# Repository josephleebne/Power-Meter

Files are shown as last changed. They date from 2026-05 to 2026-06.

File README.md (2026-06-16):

# Power Meter

This repository is a  mirror of a team project developed for **ENGG2800**. 

A high precision digital power meter designed to sample voltage and current telemetry from a load, calculate real time electrical parameters, and stream data to a localised GUI for monitoring and analysis. The system bridges custom hardware instrumentation with embedded processing and local host application interfaces.

### Finished Prototype
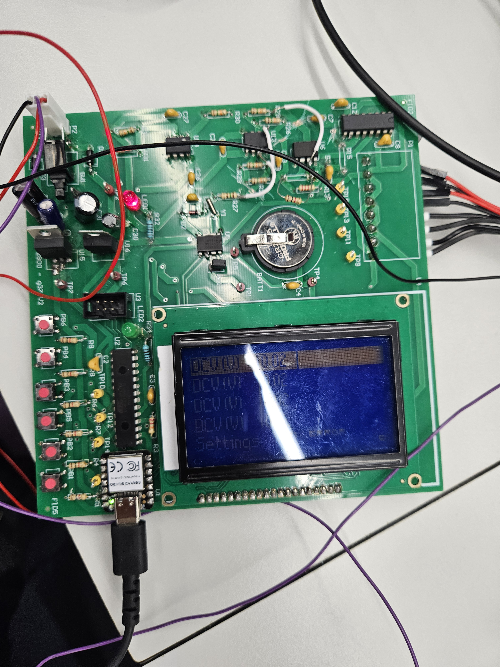
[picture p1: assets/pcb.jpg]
Finished Power Meter Prototype


### Hardware Documentation
* [PCB Artwork (PDF)](./assets/PCB_Artwork.pdf)

## The Engineering Team & Contributions

This project was developed by a collaborative 4 person engineering team. Individual technical ownership is broken down below:

* **Joseph Lee (Firmware & Analogue Electronics Engineer):** Engineered the core measurement firmware, designed and implemented the signal conditioning analogue circuits, and performed the final hardware schematic and PCB design audits to ensure production compliance. Compiled and structured the final engineering Bill of Materials.
* **Software Engineer:** Developed the desktop Graphical User Interface (GUI), built the data parsing serial communication protocols, and integrated secondary hardware timekeeping features.
* **Display Systems Engineer:** Owned the low level firmware drivers and hardware interfacing for the localised system LCD menus.
* **PCB Design Engineer:** Handled the physical PCB layout routing, electronic component soldering, and implemented safe switching circuitry for wide-range current measurements.

## My Contributions

### 1. Analogue Measurement Circuit Design
* **Signal Conditioning:** Designed and implemented a five stage pipeline matching analogue to digital converter constraints to safely process AC and DC voltage and current waveforms.
* **Iterative Prototyping:** Conducted rigorous breadboard testing and design iterations to select optimal scaling and biasing topologies (See the beautiful chaos below).

### Breadboard Prototyping and Validation Stage
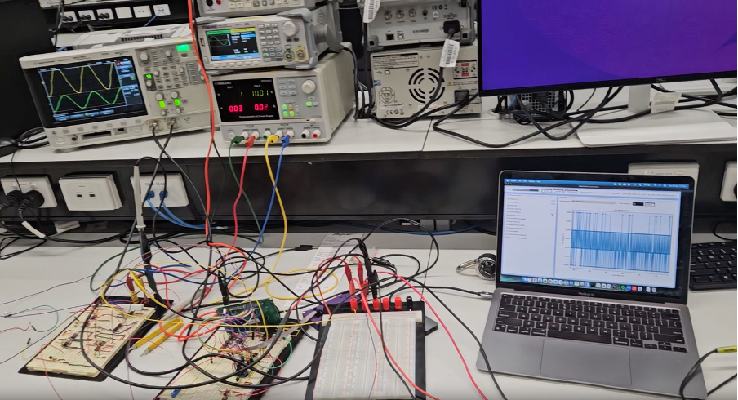
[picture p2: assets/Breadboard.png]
Breadboard Prototyping and Validation Stage


* **Hardware Debugging:** Resolved circuit loading effects by introducing active operational amplifier buffering stages.
* **Power Subsystem Redesign:** Eliminated amplifier saturation by upgrading supply rails to 10V and integrating a 5V regulator for the ATmega microcontroller and display.
* **Simulation:** Modelled all AC and DC measurement circuits using simulation software to validate operational theory prior to production.

### 2. Measurement Firmware Engineering
* **Architecture:** Developed an interrupt based sampling architecture to ensure deterministic data collection and system responsiveness.
* **Signal Processing:** Implemented low level firmware executing real time calculations, transitioning raw data into True Root Mean Square accumulation loops.
* **Precision Metrics:** Engineered efficient firmware routines to calculate frequency, power factor, and phase angles.
* **Data Streaming:** Designed serial communication protocols to stream calculated telemetry data to the host interface.

### 3. PCB Review and Documentation
* **Design Audits:** Spearheaded comprehensive hardware schematic reviews against technical standards to prevent layout errors.
* **BOM Generation:** Compiled the final engineering Bill of Materials, cross referencing datasheets to guarantee exact footprint matches and proper component sourcing.

#### Bill of Materials (BOM)
* [BOM](./assets/BOM.pdf)

## Repository Architecture

The codebase has been stripped of legacy test files and is organised strictly around the deliverables:
```text
Power-Meter/
├── .gitignore
├── embedded/           # Firmwire Files
│   ├── lcd/            # Display drivers
│   └── measurement.X/  # Core firmware workspace
└── lab_pc/             # GUI Files
│    └── GUI_new.py      # Python based user interface for telemetry rendering
│
├── PCB/                # Altium Designer Project

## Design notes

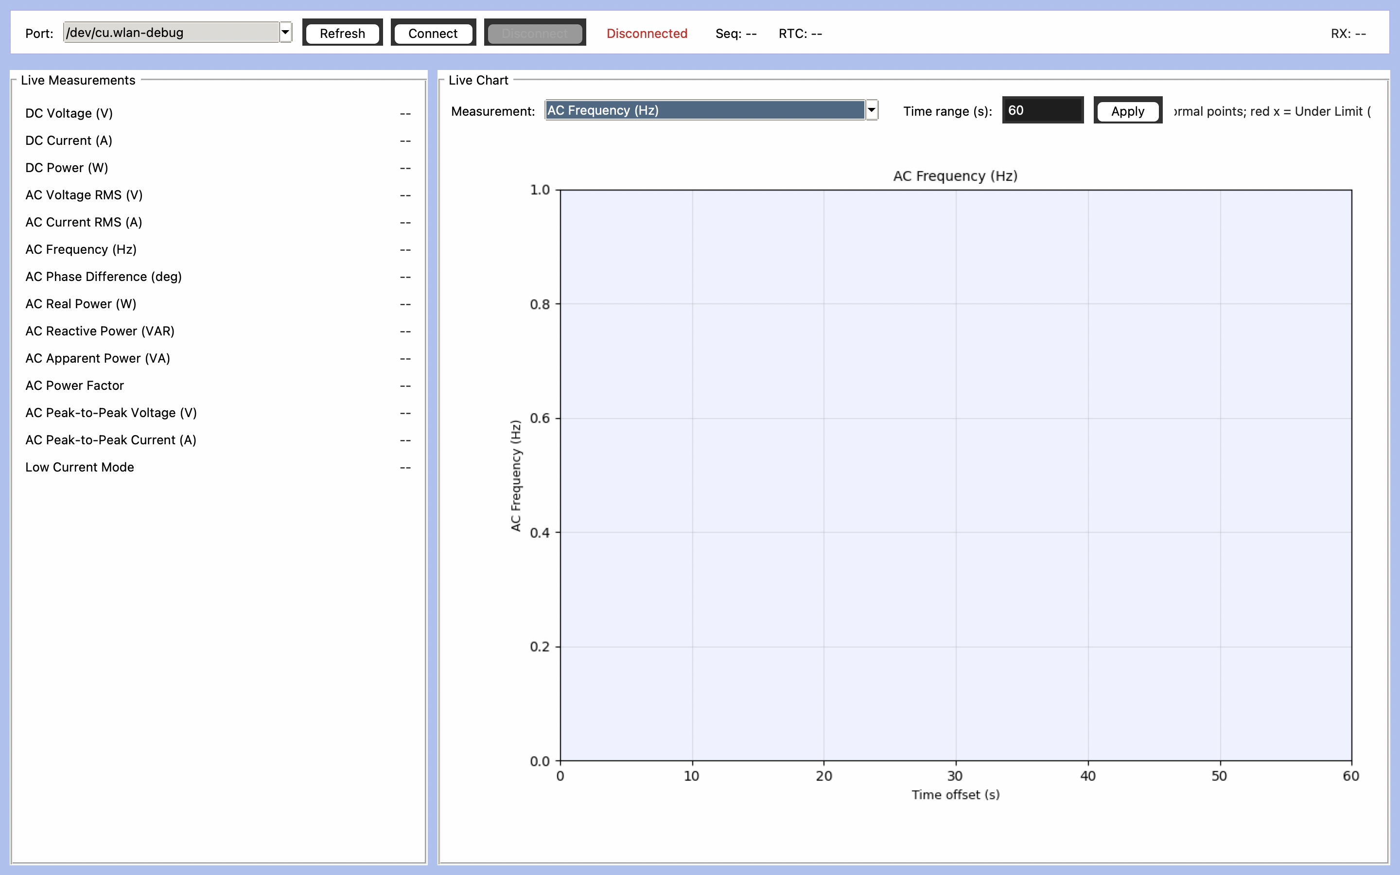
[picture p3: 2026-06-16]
assets/GUI.png

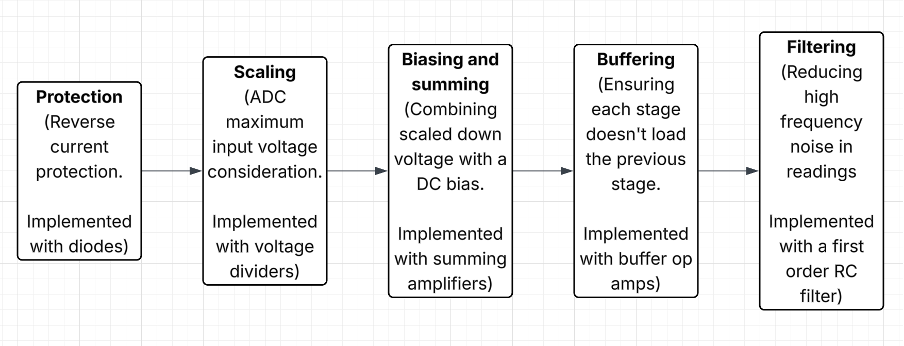
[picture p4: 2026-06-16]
assets/Signal_Conditioning_Pipeline.png

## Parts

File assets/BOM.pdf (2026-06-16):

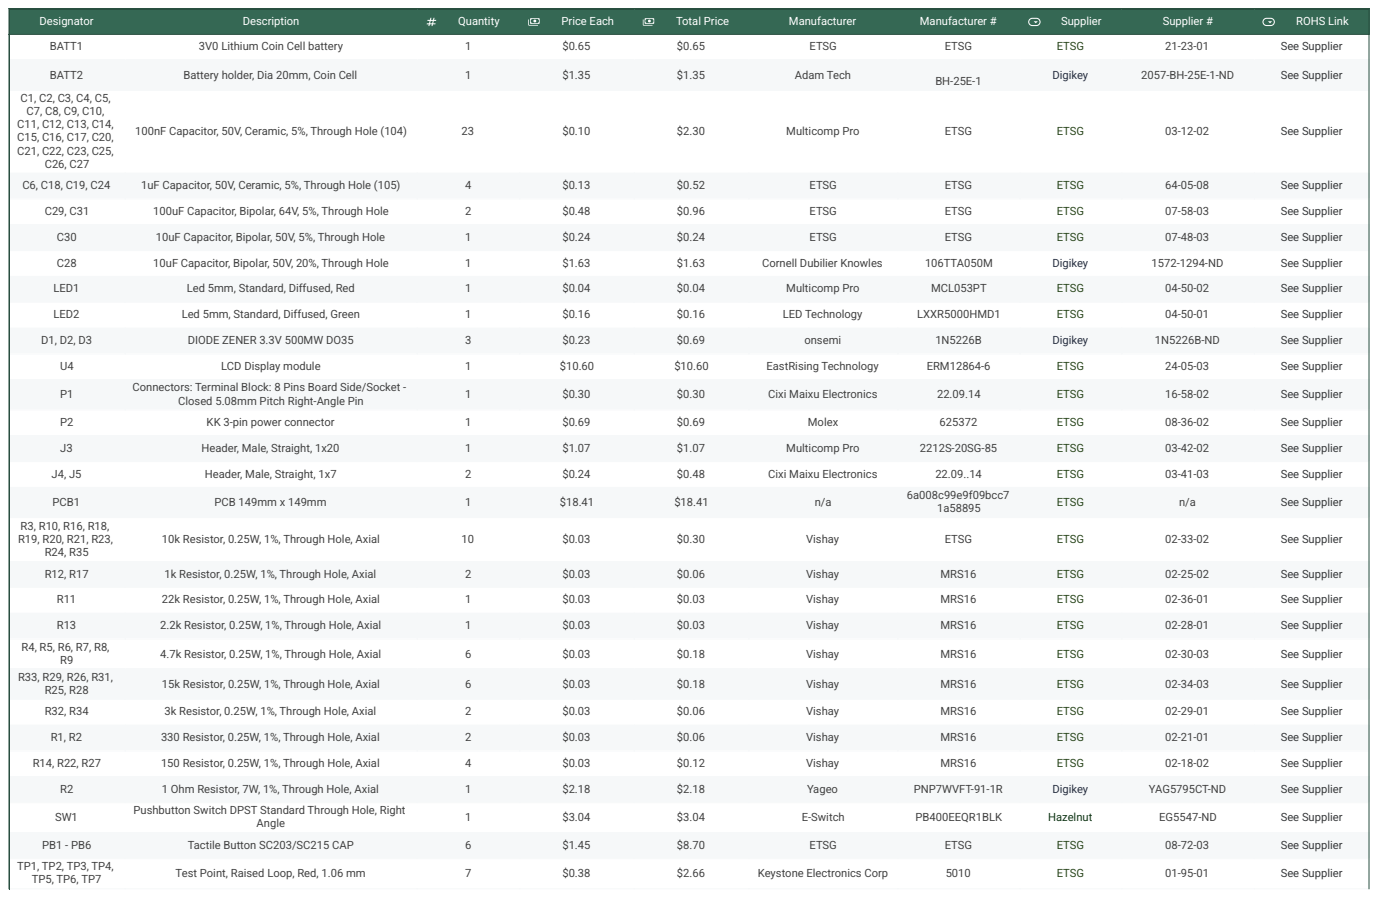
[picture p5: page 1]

Designator | Description | Quantity | Price Each | Total Price | Manufacturer | Manufacturer # | Supplier | Supplier # | ROHS Link

BATT1 | 3V0 Lithium Coin Cell battery | 1 | $0.65 | $0.65 | ETSG | ETSG | ETSG | 21-23-01 | See Supplier

BATT2 | Battery holder, Dia 20mm, Coin Cell | 1 | $1.35 | $1.35 | Adam Tech | BH-25E-1 | Digikey | 2057-BH-25E-1-ND | See Supplier

C1, C2, C3, C4, C5, C7, C8, C9, C10, C11, C12, C13, C14, C15, C16, C17, C20, C21, C22, C23, C25, C26, C27 | 100nF Capacitor, 50V, Ceramic, 5%, Through Hole (104) | 23 | $0.10 | $2.30 | Multicomp Pro | ETSG | ETSG | 03-12-02 | See Supplier

C6, C18, C19, C24 | 1uF Capacitor, 50V, Ceramic, 5%, Through Hole (105) | 4 | $0.13 | $0.52 | ETSG | ETSG | ETSG | 64-05-08 | See Supplier

C29, C31 | 100uF Capacitor, Bipolar, 64V, 5%, Through Hole | 2 | $0.48 | $0.96 | ETSG | ETSG | ETSG | 07-58-03 | See Supplier

C30 | 10uF Capacitor, Bipolar, 50V, 5%, Through Hole | 1 | $0.24 | $0.24 | ETSG | ETSG | ETSG | 07-48-03 | See Supplier

C28 | 10uF Capacitor, Bipolar, 50V, 20%, Through Hole | 1 | $1.63 | $1.63 | Cornell Dubilier Knowles | 106TTA050M | Digikey | 1572-1294-ND | See Supplier

LED1 | Led 5mm, Standard, Diffused, Red | 1 | $0.04 | $0.04 | Multicomp Pro | MCL053PT | ETSG | 04-50-02 | See Supplier

LED2 | Led 5mm, Standard, Diffused, Green | 1 | $0.16 | $0.16 | LED Technology | LXXR5000НMD1 | ETSG | 04-50-01 | See Supplier

D1, D2, D3 | DIODE ZENER 3.3V 500MW DO35 | 3 | $0.23 | $0.69 | onsemi | 1N5226B | Digikey | 1N5226B-ND | See Supplier

U4 | LCD Display module | 1 | $10.60 | $10.60 | EastRising Technology | ERM12864-6 | ETSG | 24-05-03 | See Supplier

P1 | Connectors: Terminal Block: 8 Pins Board Side/Socket -Closed 5.08mm Pitch Right-Angle Pin | 1 | $0.30 | $0.30 | Cixi Maixu Electronics | 22.09.14 | ETSG | 16-58-02 | See Supplier

P2 | KK 3-pin power connector | 1 | $0.69 | $0.69 | Molex | 625372 | ETSG | 08-36-02 | See Supplier

J3 | Header, Male, Straight, 1x20 | 1 | $1.07 | $1.07 | Multicomp Pro | 2212S-20SG-85 | ETSG | 03-42-02 | See Supplier

J4, J5 | Header, Male, Straight, 1x7 | 2 | $0.24 | $0.48 | Cixi Maixu Electronics | 22.09..14 | ETSG | 03-41-03 | See Supplier

PCB1 | PCB 149mm x 149mm | 1 | $18.41 | $18.41 | n/a | 6a008c99e9f09bcc7 1a58895 | ETSG | n/a | See Supplier

R3, R10, R16, R18, R19, R20, R21, R23, R24, R35 | 10k Resistor, 0.25W, 1%, Through Hole, Axial | 10 | $0.03 | $0.30 | Vishay | ETSG | ETSG | 02-33-02 | See Supplier

R12, R17 | 1k Resistor, 0.25W, 1%, Through Hole, Axial | 2 | $0.03 | $0.06 | Vishay | MRS16 | ETSG | 02-25-02 | See Supplier

R11 | 22k Resistor, 0.25W, 1%, Through Hole, Axial | 1 | $0.03 | $0.03 | Vishay | MRS16 | ETSG | 02-36-01 | See Supplier

R13 | 2.2k Resistor, 0.25W, 1%, Through Hole, Axial | 1 | $0.03 | $0.03 | Vishay | MRS16 | ETSG | 02-28-01 | See Supplier

R4, R5, R6, R7, R8, R9 | 4.7k Resistor, 0.25W, 1%, Through Hole, Axial | 6 | $0.03 | $0.18 | Vishay | MRS16 | ETSG | 02-30-03 | See Supplier

R33, R29, R26, R31, R25, R28 | 15k Resistor, 0.25W, 1%, Through Hole, Axial | 6 | $0.03 | $0.18 | Vishay | MRS16 | ETSG | 02-34-03 | See Supplier

R32, R34 | 3k Resistor, 0.25W, 1%, Through Hole, Axial | 2 | $0.03 | $0.06 | Vishay | MRS16 | ETSG | 02-29-01 | See Supplier

R1, R2 | 330 Resistor, 0.25W, 1%, Through Hole, Axial | 2 | $0.03 | $0.06 | Vishay | MRS16 | ETSG | 02-21-01 | See Supplier

R14, R22, R27 | 150 Resistor, 0.25W, 1%, Through Hole, Axial | 4 | $0.03 | $0.12 | Vishay | MRS16 | ETSG | 02-18-02 | See Supplier

R2 | 1 Ohm Resistor, 7W, 1%, Through Hole, Axial | 1 | $2.18 | $2.18 | Yageo | PNP7WVFT-91-1R | Digikey | YAG5795CT-ND | See Supplier

SW1 | Pushbutton Switch DPST Standard Through Hole, Right Angle | 1 | $3.04 | $3.04 | E-Switch | PB400EEQR1BLK | Hazelnut | EG5547-ND | See Supplier

PB1 - PB6 | Tactile Button SC203/SC215 CAP | 6 | $1.45 | $8.70 | ETSG | ETSG | ETSG | 08-72-03 | See Supplier

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

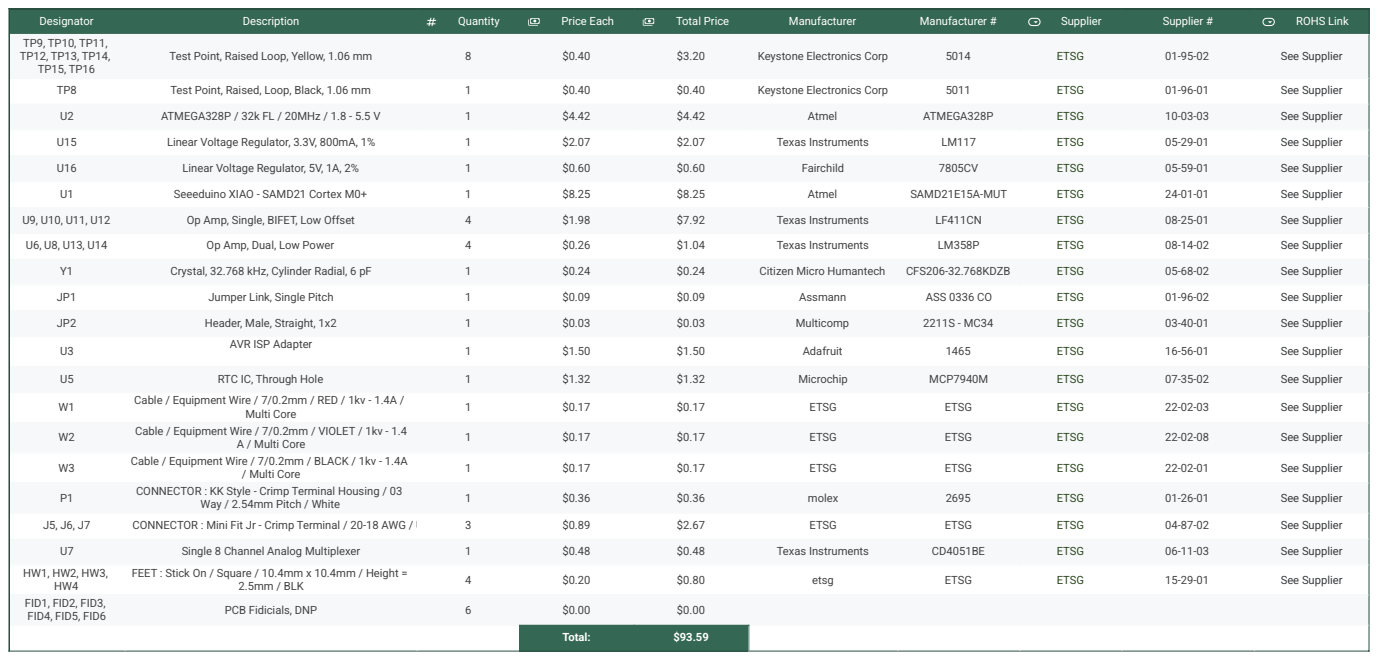
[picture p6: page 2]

Designator | Description | Quantity | Price Each | Total Price | Manufacturer | Manufacturer # | Supplier | Supplier # | ROHS Link

TP9, TP10, TP11, TP12, TP13, TP14, TP15, TP16 | Test Point, Raised Loop, Yellow, 1.06 mm | 8 | $0.40 | $3.20 | Keystone Electronics Corp | 5014 | ETSG | 01-95-02 | See Supplier

TP8 | Test Point, Raised, Loop, Black, 1.06 mm | 1 | $0.40 | $0.40 | Keystone Electronics Corp | 5011 | ETSG | 01-96-01 | See Supplier

U2 | ATMEGA328P / 32k FL / 20MHz / 1.8 - 5.5 V | 1 | $4.42 | $4.42 | Atmel | ATMEGA328P | ETSG | 10-03-03 | See Supplier

U15 | Linear Voltage Regulator, 3.3V, 800mA, 1% | 1 | $2.07 | $2.07 | Texas Instruments | LM117 | ETSG | 05-29-01 | See Supplier

U16 | Linear Voltage Regulator, 5V, 1A, 2% | 1 | $0.60 | $0.60 | Fairchild | 7805CV | ETSG | 05-59-01 | See Supplier

U1 | Seeeduino XIAO - SAMD21 Cortex M0+ | 1 | $8.25 | $8.25 | Atmel | SAMD21E15A-MUT | ETSG | 24-01-01 | See Supplier

U9, U10, U11, U12 | Op Amp, Single, BIFET, Low Offset | 4 | $1.98 | $7.92 | Texas Instruments | LF411CN | ETSG | 08-25-01 | See Supplier

U6, U8, U13, U14 | Op Amp, Dual, Low Power | 4 | $0.26 | $1.04 | Texas Instruments | LM358P | ETSG | 08-14-02 | See Supplier

Y1 | Crystal, 32.768 kHz, Cylinder Radial, 6 pF | 1 | $0.24 | $0.24 | Citizen Micro Humantech | CFS206-32.768KDZB | ETSG | 05-68-02 | See Supplier

JP1 | Jumper Link, Single Pitch | 1 | $0.09 | $0.09 | Assmann | ASS 0336 CO | ETSG | 01-96-02 | See Supplier

JP2 | Header, Male, Straight, 1x2 | 1 | $0.03 | $0.03 | Multicomp | 2211S - MC34 | ETSG | 03-40-01 | See Supplier

U3 | AVR ISP Adapter | 1 | $1.50 | $1.50 | Adafruit | 1465 | ETSG | 16-56-01 | See Supplier

U5 | RTC IC, Through Hole | 1 | $1.32 | $1.32 | Microchip | MCP7940M | ETSG | 07-35-02 | See Supplier

W1 | Cable / Equipment Wire / 7/0.2mm / RED / 1kv - 1.4A / Multi Core | 1 | $0.17 | $0.17 | ETSG | ETSG | ETSG | 22-02-03 | See Supplier

W2 | Cable / Equipment Wire / 7/0.2mm / VIOLET / 1kv - 1.4 A / Multi Core | 1 | $0.17 | $0.17 | ETSG | ETSG | ETSG | 22-02-08 | See Supplier

W3 | Cable / Equipment Wire / 7/0.2mm / BLACK / 1kv - 1.4A / Multi Core | 1 | $0.17 | $0.17 | ETSG | ETSG | ETSG | 22-02-01 | See Supplier

P1 | CONNECTOR : KK Style - Crimp Terminal Housing / 03 Way / 2.54mm Pitch / White | 1 | $0.36 | $0.36 | molex | 2695 | ETSG | 01-26-01 | See Supplier

J5, J6, J7 | CONNECTOR : Mini Fit Jr - Crimp Terminal / 20-18 AWG / Use Crimp Tool K271 3 | | $0.89 | $2.67 | ETSG | ETSG | ETSG | 04-87-02 | See Supplier

U7 | Single 8 Channel Analog Multiplexer | 1 | $0.48 | $0.48 | Texas Instruments | CD4051BE | ETSG | 06-11-03 | See Supplier

HW1, HW2, HW3, HW4 | FEET : Stick On / Square / 10.4mm x 10.4mm / Height = 2.5mm / BLK | 4 | $0.20 | $0.80 | etsg | ETSG | ETSG | 15-29-01 | See Supplier

FID1, FID2, FID3, FID4, FID5, FID6 | PCB Fidicials, DNP | 6 | $0.00 | $0.00

Total: | $93.59

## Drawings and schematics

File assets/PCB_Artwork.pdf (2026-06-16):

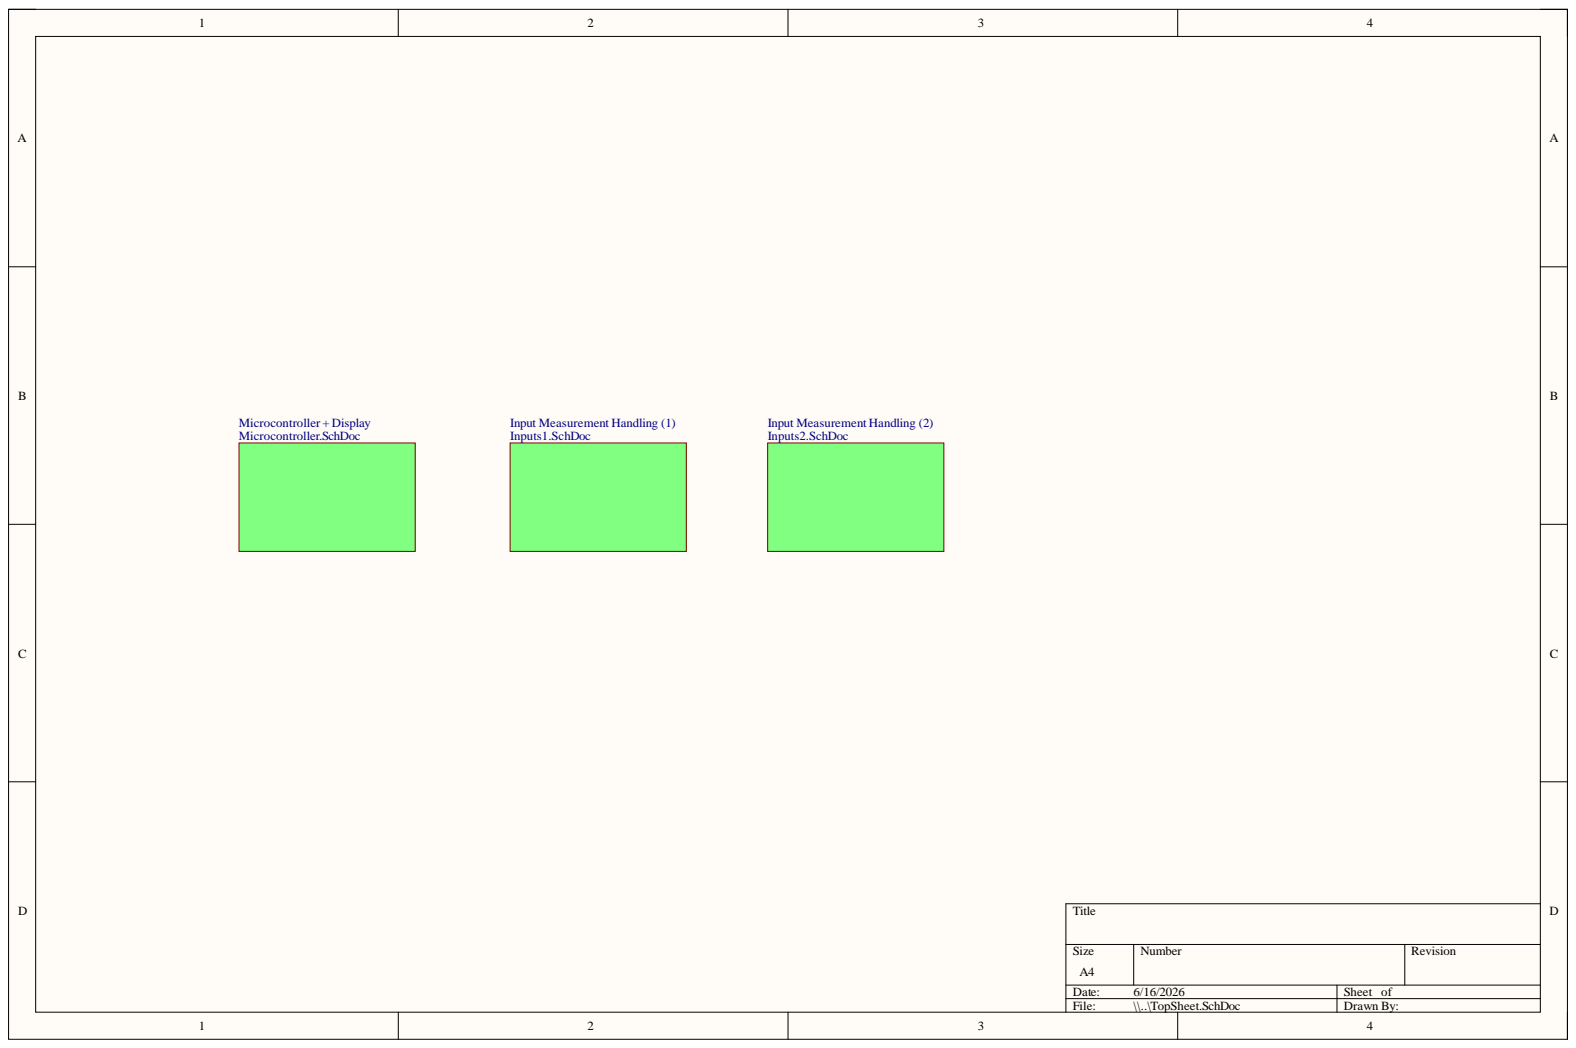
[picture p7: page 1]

Size A4 | Number | Revision

Date: 6/16/2026 | Sheet of
File: \\..\TopSheet.SchDoc | Drawn By:

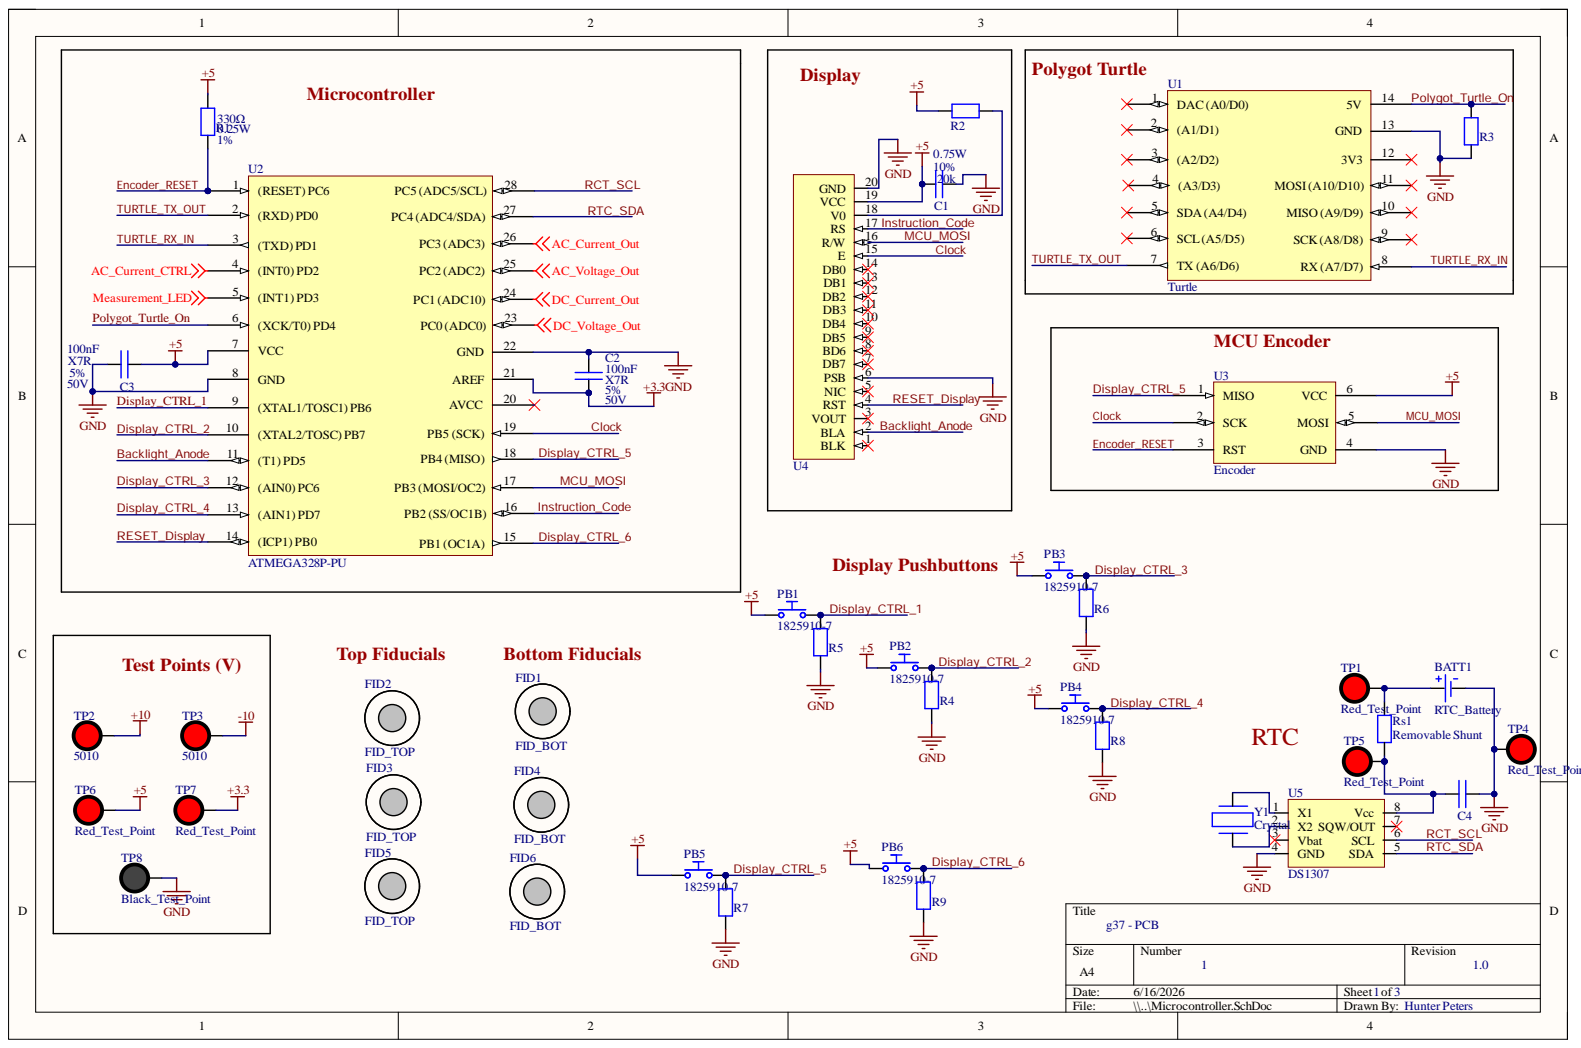
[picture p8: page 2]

Da te : 6/16/202 6 | She et of 1 3
File : \\. .\Mic rocontroll e r . S c hD o c | Dr awn B y : Hunte r P e te r s

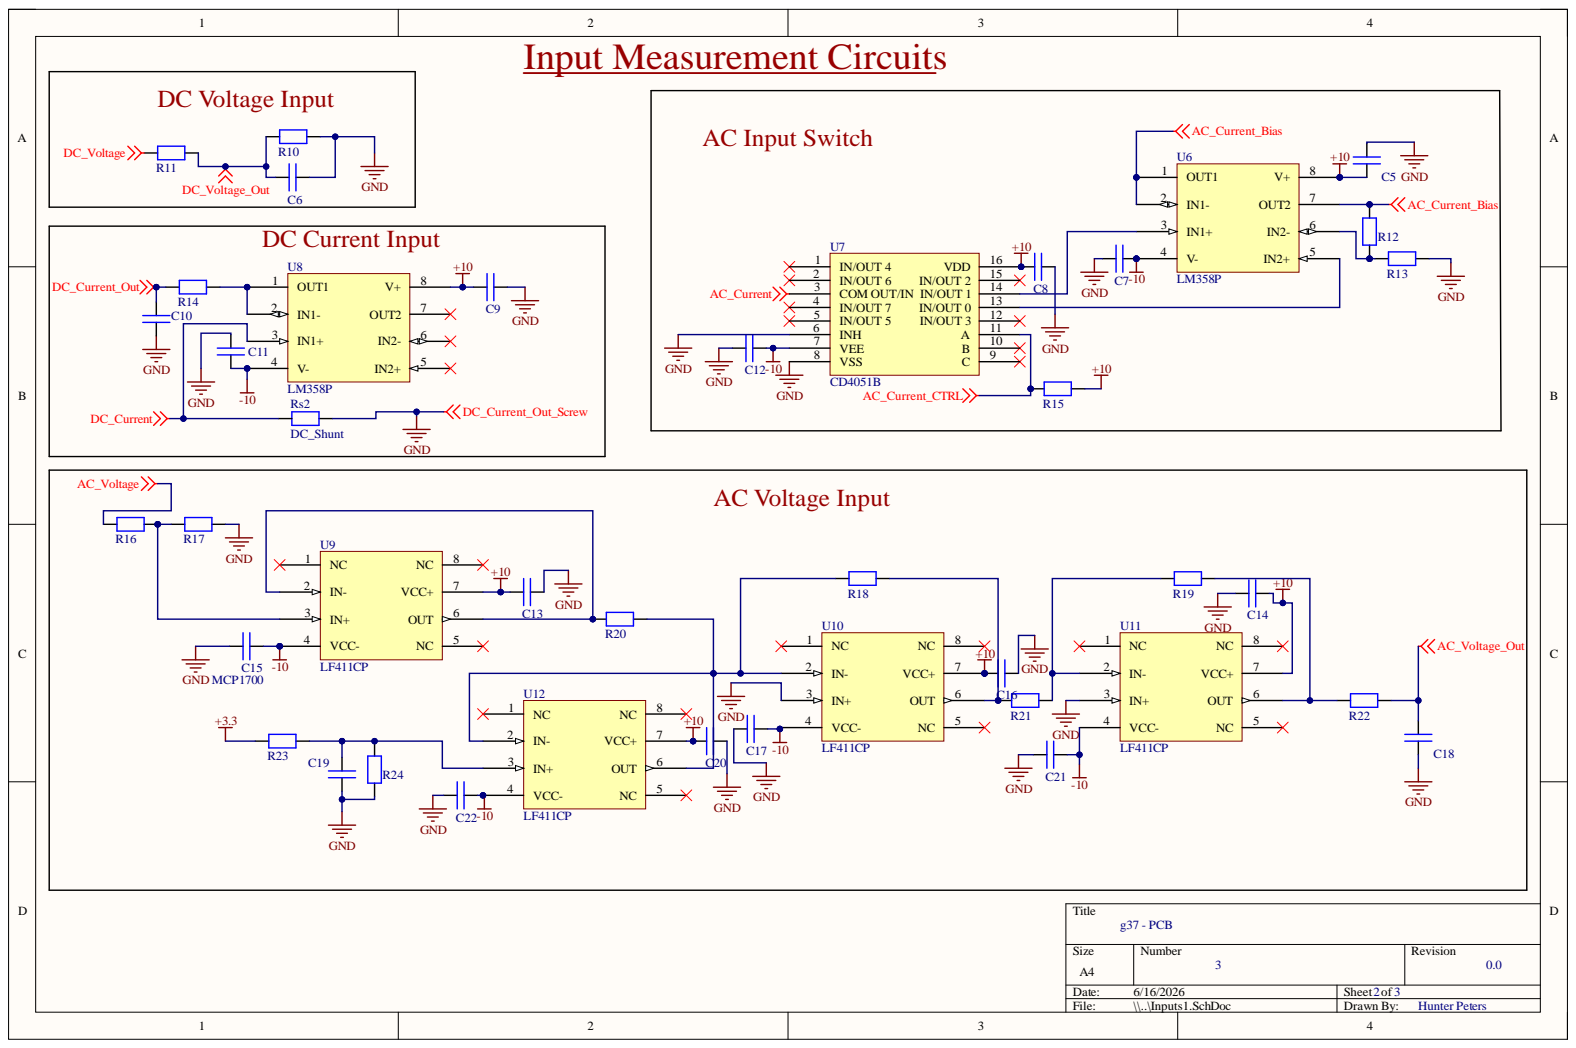
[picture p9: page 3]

Size A4 | Number 3 | Revision 0.0

Date: 6/16/2026 | Sheet of 2 3
File: \\..\Inputs1.SchDoc | Drawn By: Hunter Peters

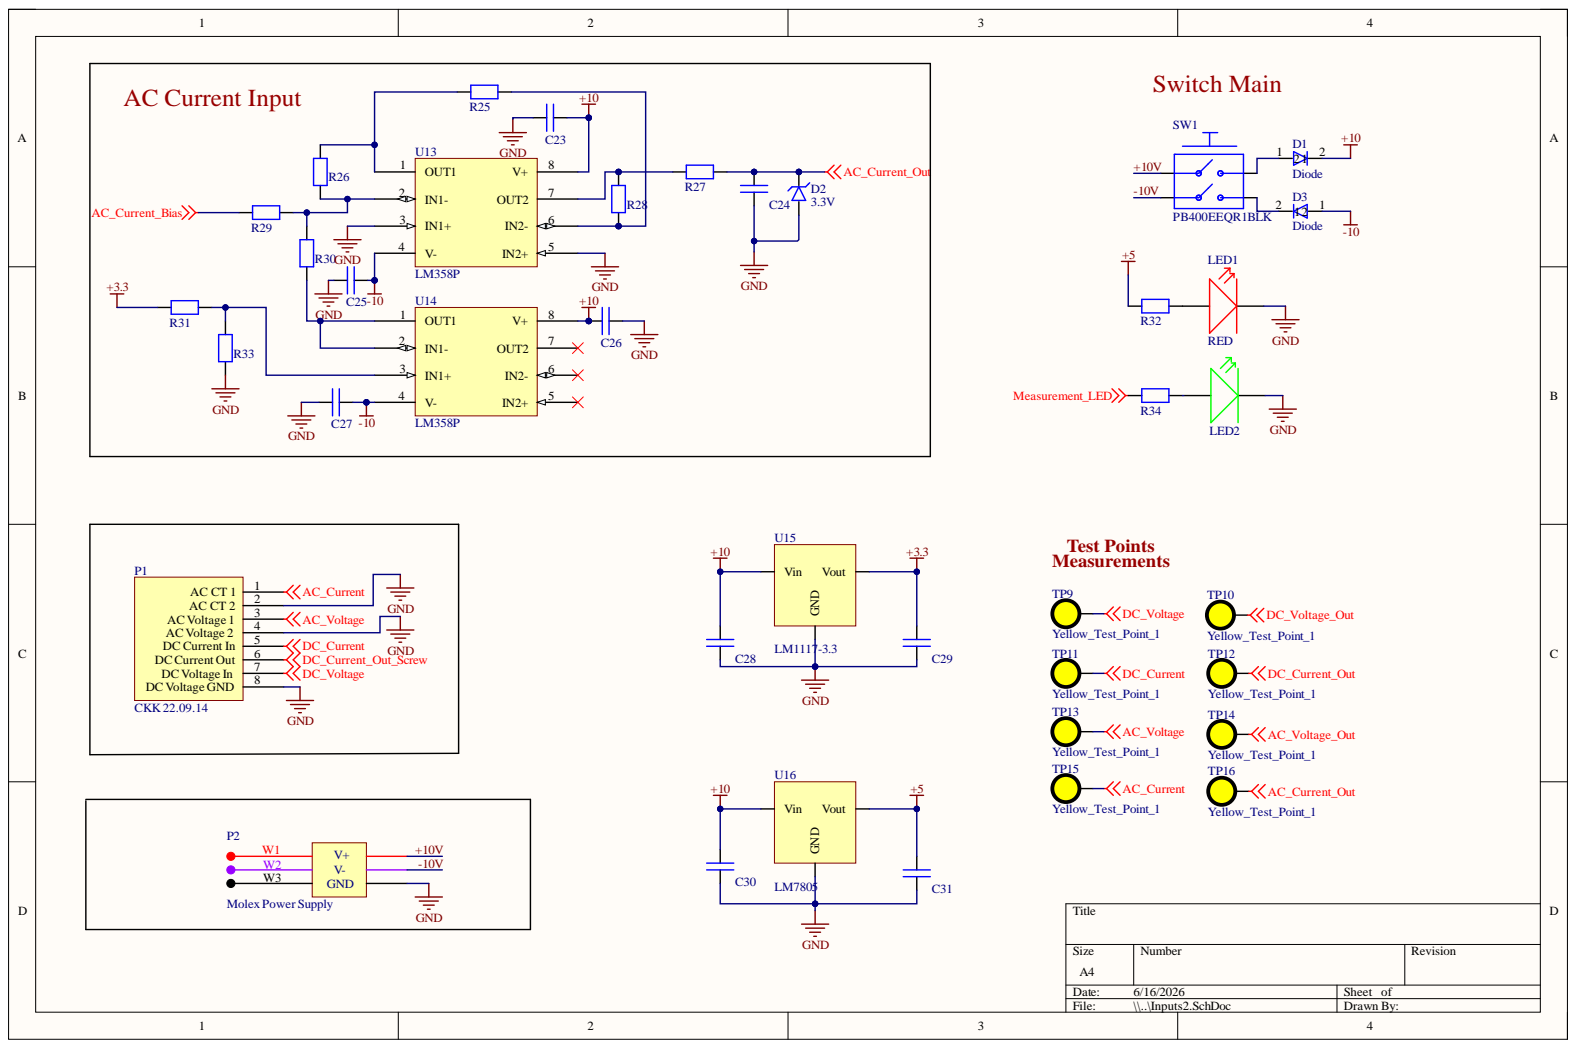
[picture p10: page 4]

U13 GND
OUT1 1

Size A4 | Number | Revision

Date: 6/16/2026 | Sheet of
File: \\..\Inputs2.SchDoc | Drawn By:

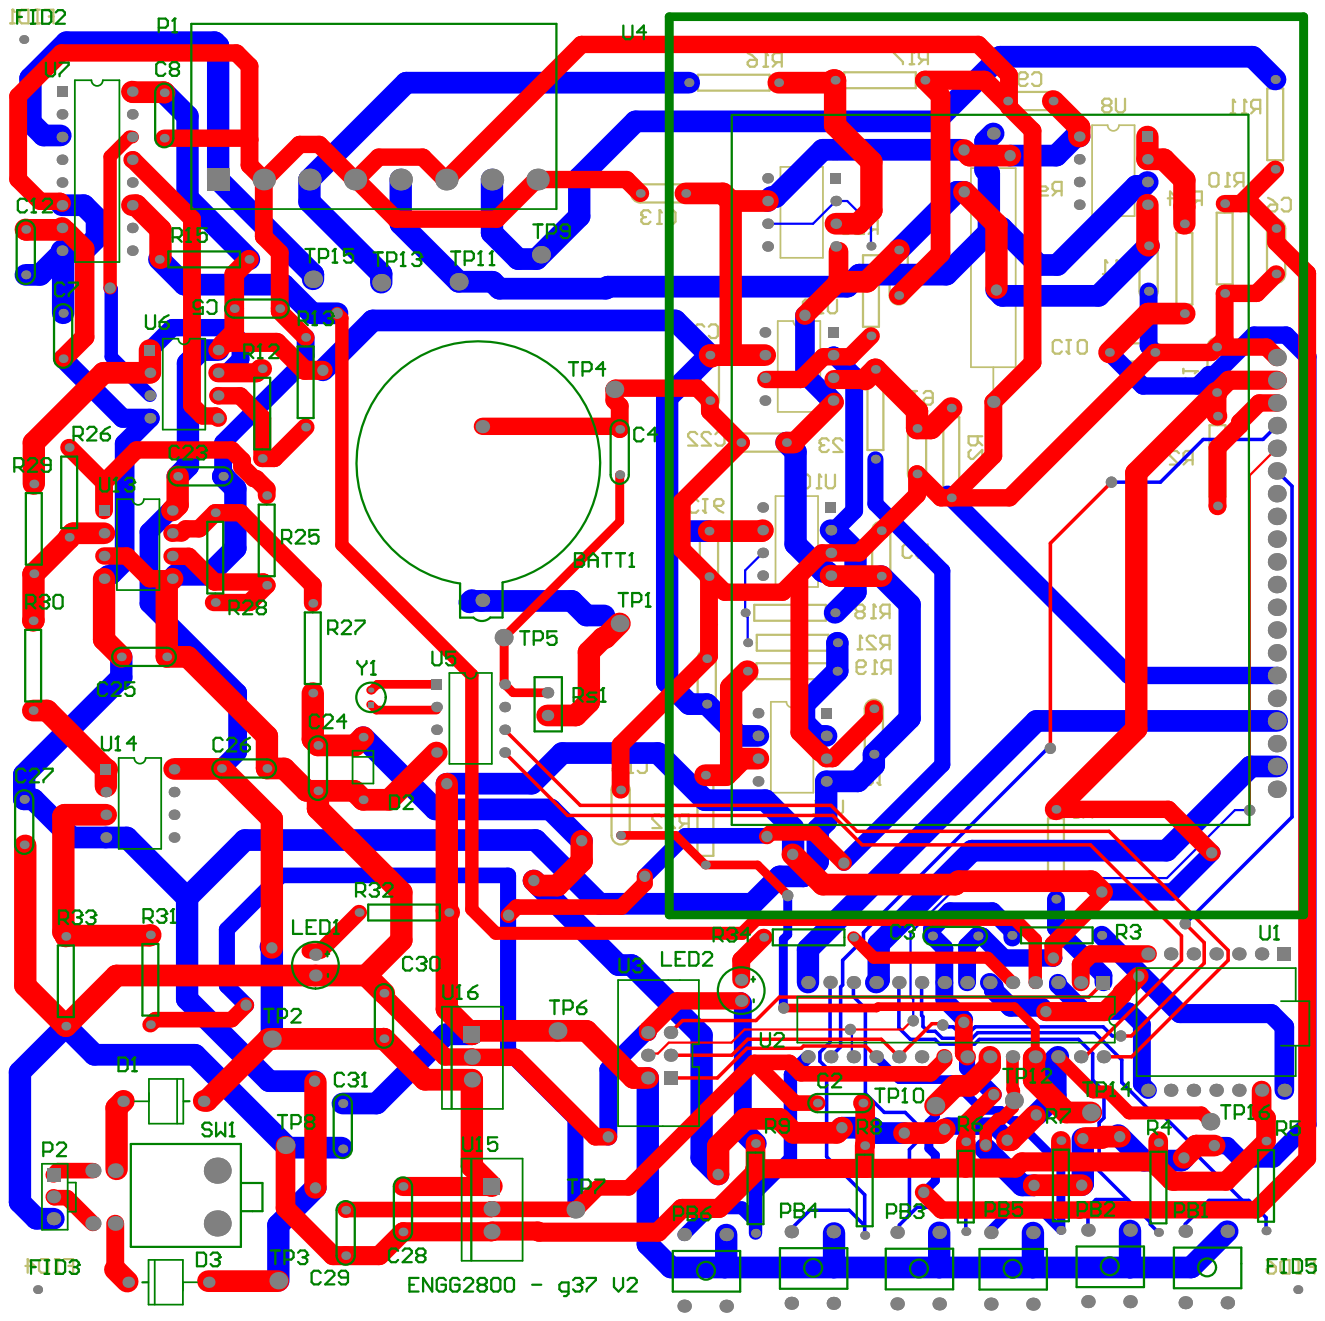
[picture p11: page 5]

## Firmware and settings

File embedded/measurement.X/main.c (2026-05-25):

// *************************      INCLUDES
// ******************************
#define F_CPU 8000000UL
#include "u8g2.h"
#include <avr/interrupt.h>
#include <avr/io.h>
#include <avr/power.h>
#include <math.h>
#include <stdint.h>
#include <stdio.h>
#include <stdlib.h>
#include <time.h>
#include <util/delay.h>

// ************************      CLOCK SPEED
// *****************************
FUSES = {
    .low
    = 0xE2, // LOW
            // {SUT_CKSEL=INTRCOSC_8MHZ_6CK_14CK_65MS,
            // CKOUT=CLEAR, CKDIV8=CLEAR}
    .high
    = 0xD9, // HIGH {BOOTRST=CLEAR,
            // BOOTSZ=2048W_3800, EESAVE=CLEAR,
            // WDTON=CLEAR, SPIEN=SET, DWEN=CLEAR,
            // RSTDISBL=CLEAR}
    .extended
    = 0xFF, // EXTENDED {BODLEVEL=DISABLED}
};

LOCKBITS = 0xFF; // {LB=NO_LOCK, BLB0=NO_LOCK,
                 // BLB1=NO_LOCK}

// ************************      LCD DEFINES
// *****************************
#define DISPLAY_CLK_DIR DDRB
#define DISPLAY_CLK_PORT PORTB
#define DISPLAY_CLK_PIN 5

#define DISPLAY_DATA_DIR DDRB
#define DISPLAY_DATA_PORT PORTB
#define DISPLAY_DATA_PIN 3

#define DISPLAY_CS_DIR DDRB
#define DISPLAY_CS_PORT PORTB
#define DISPLAY_CS_PIN 2

#define DISPLAY_DC_DIR DDRB
#define DISPLAY_DC_PORT PORTB
#define DISPLAY_DC_PIN 1

#define DISPLAY_RESET_DIR DDRB
#define DISPLAY_RESET_PORT PORTB
#define DISPLAY_RESET_PIN 0

#define ENTER (PINB & (1 << 1))
#define BACK (PINB & (1 << 4))
#define UP (PINB & (1 << 6))
#define DOWN (PINB & (1 << 7))
#define RIGHT (PIND & (1 << 6))
#define LEFT (PIND & (1 << 7))

#define P_CPU_NS (1000000000UL / F_CPU)

#define MEASUREMENT_1_ADDRESS 0
#define MEASUREMENT_2_ADDRESS 1
#define MEASUREMENT_3_ADDRESS 2
#define MEASUREMENT_4_ADDRESS 3
#define BACKLIGHT_ADDRESS 4
#define TURNS_RATIO_ADDRESS 5

#define MEASUREMENTS 13

// ************************      RTC DEFINES
// ***************************** RTC / DS1307
#define DS1307_ADDR 0x68
#define RTC_SET_ON_BOOT 0

typedef struct {
    uint8_t sec;
    uint8_t min;
    uint8_t hour;
    uint8_t dayOfWeek;
    uint8_t day;
    uint8_t month;
    uint8_t year;
    uint8_t clockHalted;
} rtc_time_t;

// *********************      UART COMMUNICATION
// **************************
#define BAUD 9600
#define UBRR_VALUE ((F_CPU / (16UL * BAUD)) - 1)
#define TX_BUFFER_SIZE 64
volatile char tx_buffer[TX_BUFFER_SIZE];
volatile uint8_t tx_head = 0;
volatile uint8_t tx_tail = 0;

// ********************      MEASUREMENT DEFINES
// *************************
#define VREF 3.3f

// Number of samples taken in one window of AC
// measurement
#define NUM_AC_SAMPLES 1000

// Measurement array
#define NO_MEASUREMENTS 15
#define MEAS_DC_VOLTAGE 0
#define MEAS_DC_CURRENT 1
#define MEAS_AC_VOLTAGE 2
#define MEAS_AC_CURRENT 3
#define MEAS_IS_LOW_CURRENT_MODE 4
#define MEAS_AC_VOLTAGE_PK_PK 5
#define MEAS_AC_CURRENT_PK_PK 6
#define MEAS_PHASE_DIFFERENCE 7
#define MEAS_POWER_FACTOR 8
#define MEAS_FREQUENCY 9
#define MEAS_DC_POWER 10
#define MEAS_AC_REAL_POWER 11
#define MEAS_AC_REACTIVE_POWER 12
#define MEAS_AC_APPARENT_POWER 13
#define MEAS_RTC_TIME 14

// Calibration values
#define AC_VOLTAGE_ERROR_RATIO 1.128
#define AC_VOLTAGE_ERROR_SUM 0.124

#define AC_CURRENT_HIGH_ERROR_RATIO 0.864
#define AC_CURRENT_HIGH_ERROR_SUM -0.375

#define AC_CURRENT_LOW_ERROR_RATIO 0.864
#define AC_CURRENT_LOW_ERROR_SUM -0.375

#define DC_VOLTAGE_ERROR_RATIO 1.545
#define DC_VOLTAGE_ERROR_SUM 0.022

#define DC_CURRENT_ERROR_RATIO 0.965
#define DC_CURRENT_ERROR_SUM 0.012

#define FREQUENCY_ERROR_RATIO 1.0f
#define FREQUENCY_ERROR_SUM 0.0f

#define PHASE_DIFFERENCE_ERROR_RATIO -1.055
#define PHASE_DIFFERENCE_ERROR_SUM -12.736

#define AC_VOLTAGE_PK_PK_ERROR_RATIO 11.439
#define AC_VOLTAGE_PK_PK_ERROR_SUM -0.0375

#define AC_CURRENT_PK_PK_ERROR_RATIO 7.669
#define AC_CURRENT_PK_PK_ERROR_SUM -0.231

// FOR FREQUENCY MEASUREMENT
#define HYSTERESIS 0.5f
#define FREQ_AVG_COUNT \
    10 // Number of cycles to be averaged
// Take the clock speed of 8 million and divide by
// the /64 prescalar
#define T1_TICK_FREQ 125000UL

// CHANNELS
#define NO_CHANNELS 4
#define DC_VOLTAGE_CHANNEL 0 // PC0
#define DC_CURRENT_CHANNEL 1 // PC1
#define AC_VOLTAGE_CHANNEL 2 // PC2
#define AC_CURRENT_CHANNEL 3 // PC3

// ********************      MEASUREMENT GLOBALS
// ************************* For DC voltage and
// current measurement
volatile uint16_t rawDCVoltageADC = 0;
volatile uint16_t rawDCCurrentADC = 0;

// For frequency and phase measurement
volatile uint32_t periodTicks = 0;
volatile uint32_t totalPeriodAccumulator = 0;
volatile uint8_t cycleCounter = 0;

volatile uint16_t lastACValue = 512;
volatile uint16_t lastACCurrentValue = 512;

volatile uint16_t lastVTimestamp = 0;
volatile uint16_t vCrossingTime = 0;
volatile uint16_t iCrossingTime = 0;

static volatile uint16_t voltageMidpoint = 512;
static volatile uint16_t currentMidpoint = 512;

// STORED VARAIBLES FOR RMS MEASUREMENT
// FOR AC VOLTAGE
volatile uint32_t acVoltageSum = 0;
volatile uint32_t acVoltageSumSq = 0;
volatile uint16_t acVoltageMin = 1023;
volatile uint16_t acVoltageMax = 0;

// FOR AC CURRENT
volatile uint32_t acCurrentSum = 0;
volatile uint32_t acCurrentSumSq = 0;
volatile uint16_t acCurrentMin = 1023;
volatile uint16_t acCurrentMax = 0;

volatile uint16_t acSampleCount = 0;
volatile uint8_t acProcessingBusy = 0;
volatile uint8_t acDataReady = 0;

// STORED VARIABLES FOR ADC READING
volatile uint8_t areReadingsReady = 0;
volatile uint8_t ADCSelectedChannel = 0;
volatile uint8_t discardNextSample = 0;

// Measurement LED blinking
volatile uint8_t isLEDOn = 0;
volatile uint32_t ledOffTimestamp = 0;
#define BLINK_DURATION_TICKS 6

// Low Current mode
#define LOW_CURRENT_THRESHOLD \
    1.0f // Low current mode turns on below 1A
uint8_t isLowCurrentMode
    = 0; // 0 means high current mode, 1 means low
         // current mode
#define LOW_CURRENT_SCALING_RATIO \
    0.1f // Current between 0-1A is amplified 10x

// ***************      UNDER LIMIT
// DEFINITIONS/FLAGS      ********************

// flag and definition for checking if AC
// voltage/current dependent measurements are UL
volatile uint8_t
    isUnderLimit; // 1 for is UL, 0 for not UL
#define UNDER_LIMIT_CODE \
    37.0f // Sending arbitrary number when UL
#define CURRENT_UNDER_LIMIT_THRESHOLD \
    0.1 // when AC current is below 0.1, show
        // UNDER_LIMIT_CODE

// *********************      EXPONENTIAL FILTER
// **************************
#define PK_PK_SMOOTHING_FACTOR 0.95f
#define DC_SMOOTHING_FACTOR 0.95f

// ***********************      RTC VARIABLES
// ****************************
volatile rtc_time_t rtcCachedTime;
volatile uint32_t rtcCachedSeconds = 0;
volatile uint8_t rtcValid = 0;
volatile uint8_t rtcTimeSet = 0;
volatile uint32_t lastRTCPoll = 0;

// ************************      TURNS RATIO
// *****************************
float turnsRatio = 26.778f; //26.778

// ******************      LCD FUNCTION PROTOTYPES
// ***********************
uint8_t u8x8_avr_delay(u8x8_t* u8x8, uint8_t msg,
    uint8_t arg_int, void* arg_ptr);
uint8_t u8x8_avr_gpio_and_delay(u8x8_t* u8x8,
    uint8_t msg, uint8_t arg_int, void* arg_ptr);
void lcd_init();
void init();
void DrawPCIcon();
void DrawTime();
void MainScreenDraw(
    float* measurements); // LCD code slightly
                          // changed by joe
void MainScreen(float* measurements);
void MeasurementSelectDraw(void);
void MeasurementSelect(float* measurements);
void SettingsDraw();
void Settings(float* measurements);
void TurnsRatioMenu();
void TurnsRatioMenuDraw();
void DrawScreen();

// *************************      RTC PROTOTYPES
// ******************************
void TWI_init(void);
uint8_t TWI_wait_for_twint(void);
uint8_t TWI_start(uint8_t address_rw);
void TWI_stop(void);
uint8_t TWI_write(uint8_t data);
uint8_t TWI_read_ack(uint8_t* data);
uint8_t TWI_read_nack(uint8_t* data);
uint8_t bcd_to_dec(uint8_t bcd);
uint8_t dec_to_bcd(uint8_t dec);
uint8_t DS1307_read_time(rtc_time_t* t);
uint8_t DS1307_set_time(const rtc_time_t* t);
uint32_t rtc_seconds_of_day(const rtc_time_t* t);
uint8_t RTC_poll_and_cache(void);

// *************************      LCD GLOBAL
// VARIABLES      ******************************
u8g2_t u8g2;
float MenuSettings[] = {
    0, 0, 0, 0, 4, 26.788
}; // Measurement 1, Measurement 2, Measurement 3,
   // Measurement 4, BacklightIndex, TurnsRatio
int MenuSettingsEEPROMAddresses[] = {
    MEASUREMENT_1_ADDRESS, MEASUREMENT_2_ADDRESS,
    MEASUREMENT_3_ADDRESS, MEASUREMENT_4_ADDRESS,
    BACKLIGHT_ADDRESS, TURNS_RATIO_ADDRESS
};

/*
DC Voltage,
DC Current,
AC Voltage RMS,
AC Current RMS,
AC Voltage Vpp,
AC Current Vpp,
        phase difference,
        power factor,
        frequency,
        DC power,
        AC real power,
        AC reactive power,
        AC apparent power
   */

char* MeasurementName[MEASUREMENTS] = { "DCV (V)",
    "DCC (A)", "ACV (V)", "ACC (A)", "ACVPP (V)",
    "ACCPP (A)", "PD", "PF", "F (Hz)", "DCP (W)",
    "ACRP (W)", "ACRRP (W)", "ACAP (W)" };

int Menu = 0; // 0 = main screen, 1 = measurement
              // select, 2 = settings, 3 = edit
              // turns ratio
int SelectPosition[2]; // 0 = row position for the
                       // main screen, 1 =
                       // secondary position used
                       // for other menus
int Backlight[] = { 0, 64, 128, 192,
    255 }; // Values for OCR0B for Backlight
int BacklightIndexCopy
    = 4; // Copy of Backlight Index
float TurnsRatioCopy
    = 26.788; // Copy of Transformer Turns Ratio
int ButtonTurn = 1; // Button turn baton

// Timer 2 variables
volatile uint32_t timer2Overflows = 0;
volatile uint8_t timer2Flag = 0;
volatile uint8_t timer2LCDRefreshCounter = 0;
volatile uint8_t LcdTick = 0;

// *************************      RTC FUNCTIONS
// ******************************
void TWI_init(void)
{
    TWSR = 0x00;
    TWBR = 32;
    TWCR = (1 << TWEN);
}

uint8_t TWI_wait_for_twint(void)
{
    uint16_t timeout = 60000;
    while (!(TWCR & (1 << TWINT))) {
        timeout--;
        if (timeout == 0)
            return 0;
    }
    return 1;
}

uint8_t TWI_start(uint8_t address_rw)
{
    TWCR = (1 << TWINT) | (1 << TWSTA)
        | (1 << TWEN);
    if (!TWI_wait_for_twint())
        return 0;

    uint8_t status = TWSR & 0xF8;
    if ((status != 0x08) && (status != 0x10))
        return 0;

    TWDR = address_rw;
    TWCR = (1 << TWINT) | (1 << TWEN);
    if (!TWI_wait_for_twint())
        return 0;

    status = TWSR & 0xF8;
    if ((status != 0x18) && (status != 0x40))
        return 0;

    return 1;
}

void TWI_stop(void)
{
    TWCR = (1 << TWINT) | (1 << TWEN)
        | (1 << TWSTO);
    _delay_us(10);
}

uint8_t TWI_write(uint8_t data)
{
    TWDR = data;
    TWCR = (1 << TWINT) | (1 << TWEN);
    if (!TWI_wait_for_twint())
        return 0;

    uint8_t status = TWSR & 0xF8;
    return (status == 0x28);
}

uint8_t TWI_read_ack(uint8_t* data)
{
    TWCR = (1 << TWINT) | (1 << TWEN)
        | (1 << TWEA);
    if (!TWI_wait_for_twint())
        return 0;
    *data = TWDR;
    return 1;
}

uint8_t TWI_read_nack(uint8_t* data)
{
    TWCR = (1 << TWINT) | (1 << TWEN);
    if (!TWI_wait_for_twint())
        return 0;
    *data = TWDR;
    return 1;
}

uint8_t bcd_to_dec(uint8_t bcd)
{
    return ((bcd >> 4) * 10) + (bcd & 0x0F);
}

uint8_t dec_to_bcd(uint8_t dec)
{
    return ((dec / 10) << 4) | (dec % 10);
}

uint8_t DS1307_read_time(rtc_time_t* t)
{
    uint8_t raw;

    if (!TWI_start((DS1307_ADDR << 1) | 0)) {
        TWI_stop();
        return 0;
    }
    if (!TWI_write(0x00)) {
        TWI_stop();
        return 0;
    }
    if (!TWI_start((DS1307_ADDR << 1) | 1)) {
        TWI_stop();
        return 0;
    }

    if (!TWI_read_ack(&raw)) {
        TWI_stop();
        return 0;
    }
    t->clockHalted = (raw & 0x80) ? 1 : 0;
    t->sec = bcd_to_dec(raw & 0x7F);

    if (!TWI_read_ack(&raw)) {
        TWI_stop();
        return 0;
    }
    t->min = bcd_to_dec(raw);

    if (!TWI_read_ack(&raw)) {
        TWI_stop();
        return 0;
    }
    t->hour = bcd_to_dec(raw & 0x3F);

    if (!TWI_read_ack(&raw)) {
        TWI_stop();
        return 0;
    }
    t->dayOfWeek = bcd_to_dec(raw);

    if (!TWI_read_ack(&raw)) {
        TWI_stop();
        return 0;
    }
    t->day = bcd_to_dec(raw);

    if (!TWI_read_ack(&raw)) {
        TWI_stop();
        return 0;
    }
    t->month = bcd_to_dec(raw);

    if (!TWI_read_nack(&raw)) {
        TWI_stop();
        return 0;
    }
    t->year = bcd_to_dec(raw);

    TWI_stop();
    return 1;
}

uint8_t DS1307_set_time(const rtc_time_t* t)
{
    if (!TWI_start((DS1307_ADDR << 1) | 0))
        return 0;
    if (!TWI_write(0x00)) {
        TWI_stop();
        return 0;
    }

    if (!TWI_write(dec_to_bcd(t->sec) & 0x7F)) {
        TWI_stop();
        return 0;
    } // clear CH bit
    if (!TWI_write(dec_to_bcd(t->min))) {
        TWI_stop();
        return 0;
    }
    if (!TWI_write(dec_to_bcd(t->hour))) {
        TWI_stop();
        return 0;
    }
    if (!TWI_write(dec_to_bcd(t->dayOfWeek))) {
        TWI_stop();
        return 0;
    }
    if (!TWI_write(dec_to_bcd(t->day))) {
        TWI_stop();
        return 0;
    }
    if (!TWI_write(dec_to_bcd(t->month))) {
        TWI_stop();
        return 0;
    }
    if (!TWI_write(dec_to_bcd(t->year))) {
        TWI_stop();
        return 0;
    }

    TWI_stop();
    return 1;
}

uint32_t rtc_seconds_of_day(const rtc_time_t* t)
{
    return ((uint32_t)t->hour * 3600UL)
        + ((uint32_t)t->min * 60UL)
        + (uint32_t)t->sec;
}

uint8_t RTC_poll_and_cache(void)
{
    rtc_time_t rtc;
    if (DS1307_read_time(&rtc)) {
        rtcCachedTime = rtc;
        rtcCachedSeconds
            = rtc_seconds_of_day(&rtc);
        rtcValid = 1;
        rtcTimeSet = rtc.clockHalted ? 0 : 1;
        return 1;
    }
    rtcValid = 0;
    rtcTimeSet = 0;
    return 0;
}

// *************************      UART FUNCTIONS
// ******************************
void UART_init(void)
{
    tx_head = 0;
    tx_tail = 0;

    UBRR0H = (unsigned char)(UBRR_VALUE >> 8);
    UBRR0L = (unsigned char)UBRR_VALUE;

    UCSR0B = (1 << TXEN0) | (1 << RXEN0);
    // Frame: 8 data bits, 2 stop bits
    UCSR0C = (1 << USBS0) | (1 << UCSZ01)
        | (1 << UCSZ00);
}

void UART_transmit(char data)
{
    uint8_t next_head
        = (tx_head + 1) % TX_BUFFER_SIZE;

    // If buffer is full, we must wait
    while (next_head == tx_tail)
        ;

    tx_buffer[tx_head] = data;
    tx_head = next_head;

    // Enable the interrupt
    UCSR0B |= (1 << UDRIE0);
}

// Process the tranmission of UART data
ISR(USART_UDRE_vect)
{
    // Still more bytes to add to queue
    if (tx_head != tx_tail) {
        // Calculate next tail position
        uint8_t next_tail
            = (tx_tail + 1) % TX_BUFFER_SIZE;
        UDR0 = tx_buffer[tx_tail];
        tx_tail = next_tail;
    } else {
        // Buffer empty, disable interrupt
        UCSR0B &= ~(1 << UDRIE0);
    }
}

void UART_print(const char* str)
{
    while (*str) {
        UART_transmit(*str++);
    }
}

void UART_print_uint(uint16_t value)
{
    char buffer[8];
    snprintf(buffer, sizeof(buffer), "%u", value);
    UART_print(buffer);
}

void UART_print_float_2dp(float value)
{
    if (value < 0) {
        UART_print("-");
        value = -value;
    }

    uint16_t scaled
        = (uint16_t)(value * 100.0f + 0.5f);
    uint16_t whole = scaled / 100;
    uint16_t frac = scaled % 100;

    char buffer[16];
    snprintf(buffer, sizeof(buffer), "%u.%02u",
        whole, frac);
    UART_print(buffer);
}

// Send the measurement array over UART
void UART_print_measurements(
    float arr[NO_MEASUREMENTS])
{
    UART_print("[");

    for (uint8_t i = 0; i < NO_MEASUREMENTS;
        i++) {
        UART_print_float_2dp(arr[i]);

        if (i < NO_MEASUREMENTS - 1) {
            UART_print(", ");
        }
    }

    UART_print("]\r\n");
}

// *************************      ADC FUNCTIONS
// ******************************

// Setup timer 1, used for measuring AC frequency.
void setup_timer1_freerun(void)
{
    // Normal mode
    TCCR1A = 0;

    // 64 prescalar, timer resets every 524ms
    TCCR1B = (1 << CS11) | (1 << CS10);
}

void setup_ADC(void)
{
    // Set voltage reference to AREF and use 10
    // bit results.
    ADMUX = (0 << REFS1) | (0 << REFS0)
        | (0 << ADLAR);

    // Enable interrupts. Set prescalar divisor to
    // 64
    ADCSRA = (1 << ADPS2) | (1 << ADPS1)
        | (1 << ADEN) | (1 << ADIE);
}

void ADC_start_conversion(void)
{
    ADCSRA |= (1 << ADSC);
}

// Takes in a number from 0 to 4, corresponding to
// an ADC Channel
void ADC_select_channel(uint8_t channel)
{
    channel &= 0x0F; // Look at lowest 4 bits
    ADMUX &= ~((1 << MUX3) | (1 << MUX2)
        | (1 << MUX1)
        | (1 << MUX0)); // Clear channel
    ADMUX |= channel;
}

uint16_t calculate_midpoint_ADC(
    uint32_t sum, uint16_t count)
{
    if (count == 0) { // Prevent 0 division
        return 0;
    }

    uint16_t mean
        = (uint16_t)((float)sum / (float)count);
    return mean;
}

void handle_frequency_logic(uint16_t reading,
    uint8_t channel, uint16_t voltageMidpoint,
    uint16_t currentMidpoint)
{
    if (channel == AC_VOLTAGE_CHANNEL) {
        int32_t voltageLowThreshold
            = (int32_t)voltageMidpoint
            - HYSTERESIS;
        int32_t voltageHighThreshold
            = (int32_t)voltageMidpoint
            + HYSTERESIS;

        // Detect zero Crossing for voltage
        //(was below the lower bound and is now
        // above the high bound)
        if ((lastACValue <= voltageLowThreshold)
            && (reading > voltageHighThreshold)) {
            // Take the timestamp of this zero
            // crossing and calculate time from
            // previous crossing
            uint16_t currentTime = TCNT1;
            uint16_t duration
                = currentTime - lastVTimestamp;
            lastVTimestamp = currentTime;
            vCrossingTime = currentTime;

            // Update the running total of
            // periods, to be averaged
            totalPeriodAccumulator += duration;
            cycleCounter++;

            if (cycleCounter >= FREQ_AVG_COUNT) {
                periodTicks
                    = totalPeriodAccumulator;
                totalPeriodAccumulator = 0;
                cycleCounter = 0;
            }
        }
        lastACValue = reading;
    }

    if (channel == AC_CURRENT_CHANNEL) {
        int32_t currentLowThreshold
            = (int32_t)currentMidpoint
            - HYSTERESIS;
        int32_t currentHighThreshold
            = (int32_t)currentMidpoint
            + HYSTERESIS;

        // Detect zero Crossing for current
        //(was below the lower bound and is now
        // above the high bound)
        if ((lastACCurrentValue
                <= currentLowThreshold)
            && (reading > currentHighThreshold)) {
            // Take the timestamp
            iCrossingTime = TCNT1;
        }
        lastACCurrentValue = reading;
    }
}
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
int main(void)
{
    // Initialisations
    lcd_init();
    init();
    UART_init();
    init_MCU_GPIO();
    TWI_init();

    // This array will be sent via serial
    float measurements[NO_MEASUREMENTS]
        = { UNDER_LIMIT_CODE };

    ADC_start_conversion();
    ADC_select_channel(DC_VOLTAGE_CHANNEL);
    sei();

#if RTC_SET_ON_BOOT
    {
        rtc_time_t setTime;
        setTime.sec = 0;
        setTime.min = 30;
        setTime.hour = 14;
        setTime.dayOfWeek = 2;
        setTime.day = 6;
        setTime.month = 5;
        setTime.year = 26;
        setTime.clockHalted = 0;
        DS1307_set_time(&setTime);
    }
#endif
    RTC_poll_and_cache();

    while (1) {
        // Process new measurement data if the
        // window is ready
        check_measurement_LED();
        if (process_measurements(measurements)) {
            UART_print_measurements(measurements);
            trigger_measurement_LED();
        }
        check_low_current_mode(
            measurements[MEAS_AC_CURRENT]);

        // *************************      LCD CODE
        // ******************************

        if (LcdTick) {
            u8g2_ClearBuffer(&u8g2);
        }
        if (!Menu) { // The different menu
                     // screens.
            MainScreen(measurements);
        } else if (Menu == 1) {
            MeasurementSelect(measurements);
        } else if (Menu == 2) {
            Settings(measurements);
        } else if (Menu == 3) {
            TurnsRatioMenu();
        }

        if (LcdTick) {
            u8g2_SendBuffer(&u8g2);
            LcdTick = 0;
        }
    }
}

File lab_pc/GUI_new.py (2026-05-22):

"""ENGG2800 Power Meter PC software.

This program receives measurement arrays from the AVR over a serial port and
updates a live Tkinter display.  The AVR sends one Python-list-formatted line
for each sample, for example:

    [3.14, 0.52, 9.80, 0.95, 1, 18.6, 0.42,
     12.3, 0.87, 50.0, 1.63, 9.55, 1.38, 9.65, 3600]

Index mapping:
     0  DC Voltage (V)
     1  DC Current (A)
     2  AC Voltage RMS (V)
     3  AC Current RMS (A)
     4  Low Current Mode Flag
        (0 = high current mode, 1 = low current mode)
     5  AC Voltage Vpp (V)
     6  AC Current Vpp (A)
     7  Phase Difference (deg)
     8  Power Factor
     9  Frequency (Hz)
    10  DC Power (W)
    11  AC Real Power (W)
    12  AC Reactive Power (VAR)
    13  AC Apparent Power (VA)
    14  RTC time (seconds since midnight)

The current AVR firmware only transmits data.  It does not enable UART
reception, and it does not parse a PC time-sync command.  Therefore this GUI
only displays the RTC value sent by the AVR.

Special values:
    PLACEHOLDER_VALUE (37) -> measurement not yet available
    UL_CODE (37)           -> under-limit marker for selected AC values
"""

import ast
import queue
import threading
import time
import tkinter as tk
from tkinter import ttk

import matplotlib

# TkAgg must be selected before importing the Tkinter canvas backend.
matplotlib.use("TkAgg")

import serial  # noqa: E402
import serial.tools.list_ports  # noqa: E402
from matplotlib.backends.backend_tkagg import FigureCanvasTkAgg  # noqa: E402
from matplotlib.figure import Figure  # noqa: E402

# Serial-port settings.  These values must match the AVR UART configuration.
BAUD_RATE = 9600
SERIAL_TIMEOUT_S = 0.1

# Main window settings.
WINDOW_TITLE = "ENGG2800 Power Meter"
WINDOW_GEOMETRY = "1380x820"

# Plot time-range limits, in seconds.
MIN_TIME_RANGE_S = 10
MAX_TIME_RANGE_S = 3600
DEFAULT_TIME_RANGE_S = 60


# AVR now uses 37 as the default placeholder / UL code.
PLACEHOLDER_VALUE = 37
PLACEHOLDER_TOL = 0.0001

# The AVR writes 37 into selected AC-current-related measurements when they
# are under the current threshold.  Do not apply this code to every field,
# because other measurements may legitimately have the numeric value 37.
UL_CODE = 37
UL_MEASUREMENT_INDICES = {
    3,   # AC Current RMS (A).
    6,   # AC Current Vpp (A).
    7,   # Phase Difference (deg).
    8,   # Power Factor.
    11,  # AC Real Power (W).
    12,  # AC Reactive Power (VAR).
    13,  # AC Apparent Power (VA).
}

# GUI colour constants are kept together so the theme is easy to change.
COLOR_BG = "#abc1f0"
COLOR_PANEL = "#fefefe"
COLOR_BORDER = "#b2b2ef"
COLOR_TEXT = "#000000"
COLOR_SUBTEXT = "#222222"
COLOR_GREEN = "#2e7d32"
COLOR_ORANGE = "#ef6c00"
COLOR_RED = "#c62828"
COLOR_PLOT_BG = "#eef2ff"
COLOR_PLOT_LINE = "#1565c0"

# Each tuple contains the display name, AVR array index, and display format.
DISPLAY_MEASUREMENTS = [
    ("DC Voltage (V)", 0, "{:.2f}"),
    ("DC Current (A)", 1, "{:.2f}"),
    ("DC Power (W)", 10, "{:.2f}"),

    ("AC Voltage RMS (V)", 2, "{:.2f}"),
    ("AC Current RMS (A)", 3, "{:.2f}"),

    ("AC Frequency (Hz)", 9, "{:.2f}"),
    ("AC Phase Difference (deg)", 7, "{:.2f}"),

    ("AC Real Power (W)", 11, "{:.2f}"),
    ("AC Reactive Power (VAR)", 12, "{:.2f}"),
    ("AC Apparent Power (VA)", 13, "{:.2f}"),

    ("AC Power Factor", 8, "{:.3f}"),

    ("AC Peak-to-Peak Voltage (V)", 5, "{:.2f}"),
    ("AC Peak-to-Peak Current (A)", 6, "{:.2f}"),

    ("Low Current Mode", 4, "{}"),
]

MEASUREMENTS = [measurement[0] for measurement in DISPLAY_MEASUREMENTS]


class SerialManager:
    """Own the serial port and run a background reader thread."""

    def __init__(self):
        self.ser = None
        self.thread = None
        self.running = False
        self.queue = queue.Queue()
        self.lock = threading.Lock()

    def connect(self, port: str):
        """Open a serial port and start the reader thread."""
        with self.lock:
            if self.ser and self.ser.is_open:
                raise RuntimeError("Serial port is already connected")

            self.ser = serial.Serial(
                port,
                BAUD_RATE,
                timeout=SERIAL_TIMEOUT_S,
            )
            self.running = True
            self.thread = threading.Thread(
                target=self._reader,
                daemon=True,
            )
            self.thread.start()

    def disconnect(self):
        """Close the serial port and stop the reader thread."""
        with self.lock:
            self.running = False
            ser = self.ser
            thread = self.thread

        try:
            if ser and ser.is_open:
                ser.close()
        except serial.SerialException:
            pass
        except OSError:
            pass

        if thread and thread.is_alive():
            thread.join(timeout=0.2)

        with self.lock:
            self.ser = None
            self.thread = None
            self.running = False

    def _reader(self):
        """Read complete serial lines and place them on the queue."""
        while True:
            with self.lock:
                running = self.running
                ser = self.ser

            if not running or ser is None or not ser.is_open:
                break

            try:
                raw = ser.readline()
                if not raw:
                    continue

                # Bad bytes are replaced so one corrupt byte cannot stop the
                # GUI from receiving later serial samples.
                line = raw.decode("utf-8", errors="replace").strip()
                if line:
                    self.queue.put(line)
            except (serial.SerialException, OSError) as exc:
                with self.lock:
                    still_running = self.running

                # Only report the error when the disconnect was not requested
                # by the user.
                if still_running:
                    self.queue.put(
                        {
                            "type": "__error__",
                            "msg": str(exc),
                        }
                    )
                break
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

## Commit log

2026-03-23 Code now blinks LED 3 times before and after drawing - debugging purposes
2026-04-16 Replace measurement.X project files
    [main.c]
2026-04-17 DC Voltage outputs to serial
2026-04-20 Made measurements interrupts driven. UART is still blocking
2026-04-25 Added AC voltage and AC Current (High) measurement functionality.
2026-04-25 Changed the measurement array format to include DC power
2026-04-27 Added timer (prints every ~30ms)
2026-04-28 Slight calibrations to measurements
2026-04-28 Added calibrations for measurements
2026-04-28 Added phase difference functionality, power factor functionality
2026-04-28 Fixed bugs in frequency
    [main.c]
2026-05-03 Made some new code to try and fix the ? issue. Untested.
    [main.c]
2026-05-05 Switched frequency measurement to timer 2.
2026-05-05 Fixed a bug i think
    [main.c]
2026-05-12 Fixed a bug with DC measurement. Optimised UL logic
    [main.c]
2026-05-12 added functionality for dc power, real, reactive and apparent power
2026-05-19 Added measurement LED blinking logic. Added current high/low logic. Note: freq measurement (might) be off during low current
2026-05-21 Added functionality for pk-pk voltage.
2026-05-21 Properly calculated pk-pk measurements, and added a exponential filter to smooth things out
2026-05-24 Reversed button changes, added exponential filter to DC measurements. Fixed a bug with pk-pk measurements.
    [main.c]
2026-06-16 Edits to README.md, added PCB files
    [ENGG2800PCBSCHV3.PrjPcb, Inputs1.SchDoc, Inputs2.SchDoc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]
